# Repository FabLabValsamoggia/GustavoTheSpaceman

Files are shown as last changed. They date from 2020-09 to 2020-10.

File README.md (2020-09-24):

# Gustavo the Spaceman

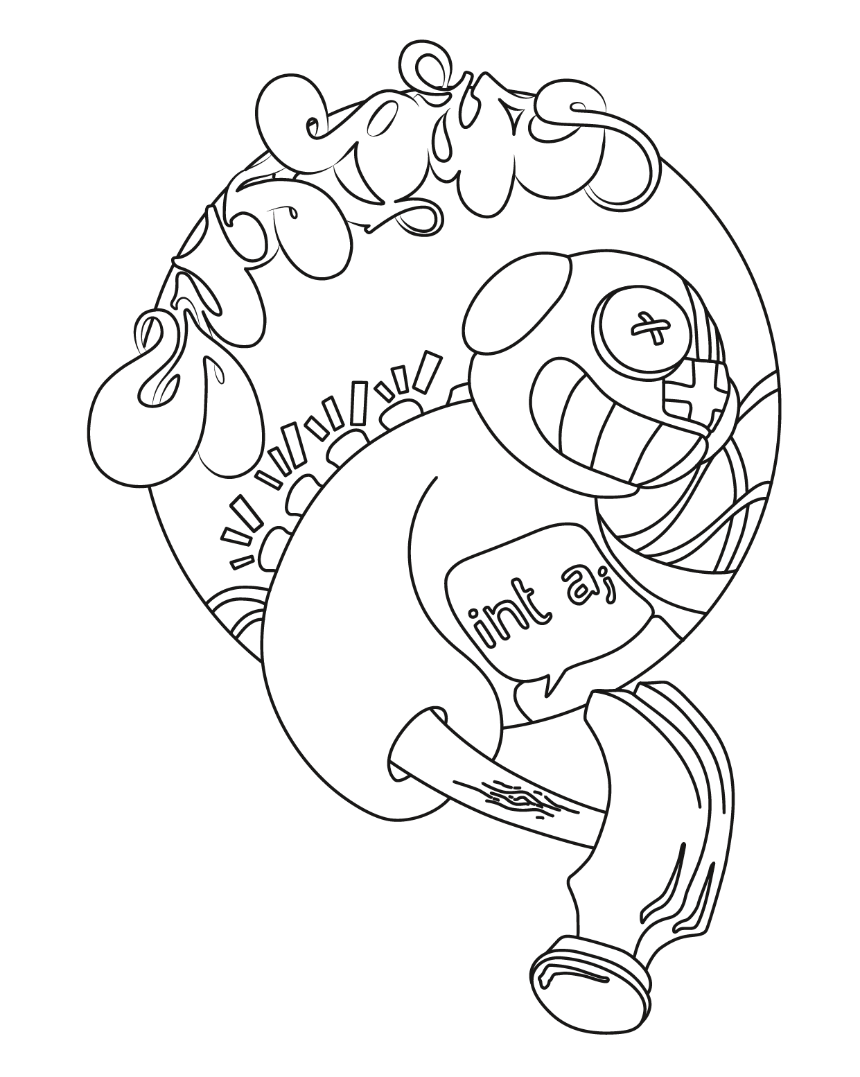
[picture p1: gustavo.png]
Gustavo


developed with ♥ by FabLab Valsamoggia

**Gustavo the spaceman** is an educational puppet kit that can help educators and teachers to teach and experiment 3D printing, electronics and coding with children. Students can customize the puppet by adding details and tools using a 3D modeling software. Then with Arduino IDE and Blockly they can program lights and sounds to create their own character. The kit is made of a 3D printed puppet with some holes for additional parts, one Arduino Nano with USB cable, a shield with 16 LEDs and 4 buttons, a small speaker and a miniSD card reader to upload sounds.

## Contributing
Pull requests are welcome. For major changes, please open an issue first to discuss what you would like to change.

Please make sure to update tests as appropriate.

## License
[MIT](https://choosealicense.com/licenses/mit/)

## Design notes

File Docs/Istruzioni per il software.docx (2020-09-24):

Istruzioni per i vari software

1. Caricare le librerie in Arduino: ci sono due modi per caricare le librerie
  a. Metodo veloce (se è presente connessione wifi):
    i. Aprire IDE Arduino
    ii. andare in Sketch → #include librerie → gestione librerie
    iii. Nella schermata che appare cercare
      1. Adafruit NeoPixel (libreria per i led creata da Adafruit)
      2. DFRobotDFPlayerMini (libreria per il modulo mp3 da DFRobot)
  b. Metodo meno veloce (copiare le librerie da google drive (nella cartella Librerie Arduino) in Documenti → Arduino → libraries
2. Alcune note per i programmi:
  a. Tasti_e_Led: il programma setta i colori dei led (tutti e 16) del colore desiderato. Per farlo le istruzioni importanti sono

red = 0;
green = 0;
blue = 75;
matrix_color = matrix.Color(red, green, blue);
for (int i = 0; i < MATRIX_NLED; i++)
{
matrix.setPixelColor(i, matrix_color);
matrix.show();
}

red, green, blue settano il colore dei led in formato RGB; tutte e tre possono assumere valori da 0 a 255. Essi inoltre controllano la luminosità dei led . Per esempio red = 75, green = 0, blue = 0 e red = 255, green = 0, blue = 0 creano entrambi il colore rosso, ma il secondo sarà molto più luminoso.

matrix.Color mischia i tre colori.

Il ciclo for serve per accendere tutti i led. In realtà si possono accendere anche solo alcuni led o anche led singoli per esempio

for (int i = 0; i < 4; i++)
{
matrix.setPixelColor(i, matrix_color);
matrix.show();
}

accende solo i primi 4 led mentre

matrix.setPixelColor(7, matrix_color);
matrix.show();

accende solo il led numero 7

Per spegnere i led basta settare

red = 0;
green = 0;
blue = 0;
matrix_color = matrix.Color(red, green, blue);

b. Tasti_e_mp3: qui c’è poco da aggiungere. Le istruzioni sono quelle e devono essere così eseguite altrimenti non funzionano. Nell’ esempio completo di libreria però (accessibili dall’IDE arduino tramite file→ esempi→ DFRobotMini→ FullFunction) sono presenti tutte le istruzioni che puoi far eseguire al modulo mp3.

Nota Bene: nella cartella drive, all’interno di mp3Completo ho inserito una cartella microSD; all’interno c’è come devono essere inseriti i brani per fare in modo che vengano letti correttamente. In pratica dentro la SD bisogna creare una cartella mp3 e all’interno rinumerare i suoni in 0001, 0002 ecc

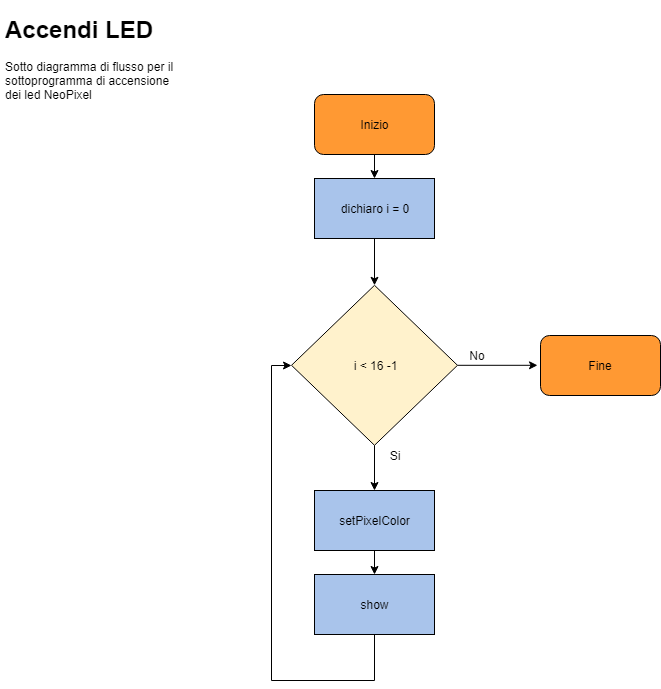
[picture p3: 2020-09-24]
Docs/Accendi Led.png

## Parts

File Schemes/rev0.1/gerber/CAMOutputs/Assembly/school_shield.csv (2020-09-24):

Qty | Value | Device | Package | Parts | Description | MPN | OC_FARNELL | OC_NEWARK | PACKAGE | PROD_ID | SPICEPREFIX | SUPPLIER
1 |  | 47346-0001 | MOLEX_47346-0001 | J1 | CONN RCPT 5POS MICRO USB R/A SMD | 47346-0001 | 1568026 | 47M0505 | 5 POS MICRO USB R/A |  | X | MOLEX
1 |  | DIODESMA | SMA-DIODE | D1 | Diode
2 |  | FE08-1SMD | FE08_SMD | SV3, SV4 | FEMALE HEADER
2 |  | FE15-1SMD | FE15_SMD | SV1, SV2 | FEMALE HEADER
14 | 10K S | R-EU_R0805 | R0805 | R1, R3, R5, R7, R9, R10, R12, R13, R15, R18, R19, R20, R21, R22 | RESISTOR, European symbol
1 | 10R S | R-EU_R0805 | R0805 | R2 | RESISTOR, European symbol
2 | 10uF | C-EUC0805 | C0805 | C203, C205 | CAPACITOR, European symbol
1 | 10uF S | C-EUC0805 | C0805 | C1 | CAPACITOR, European symbol
2 | 1K S | R-EU_R0805 | R0805 | R16, R17 | RESISTOR, European symbol
4 | 1uF | C-EUC0805 | C0805 | C2, C3, C4, C202 | CAPACITOR, European symbol
1 | 330R S | R-EU_R0805 | R0805 | R6 | RESISTOR, European symbol
1 | 53047-02 | 53047-02 | 53047-02 | X1 | CONNECTOR
1 | FABLAB | FABLAB | FABLAB | U$1
1 | LM4871M | LM4871M | SOIC127P600X175-8N | U1 | Power Amplifier | LM4871M | 1468873 | 41K5780 | SOIC-8 |  |  | NationalSemiconductor
1 | OSHW-LOGOMINI | OSHW-LOGOMINI | OSHW-LOGO-MINI | LOGO1 | Open Source Hardware Logo
4 | PHOTOCELLPTH | PHOTOCELLPTH | PHOTOCELL | R4, R8, R11, R14 | CdS photoresistor. This is a low cost way to detect light levels. Resistance decreases with more incoming light. SparkFun SKU: SEN-09088
4 | SMD_SWT | SWITCH-MOMENTARY-2SMD-4 | TACTILE_SWITCH_TALL | S1, S2, S3, S4 | Various NO switches- pushbuttons, reed, etc |  |  |  |  | SWCH-11966
1 | Si2309DS | MOSFET-PCHANNELSMD | SOT23-3 | Q1 | Generic PMOSFET
16 | WS2812B_ALT | WS2812B_ALT | WS2812B | LED1, LED2, LED3, LED4, LED5, LED6, LED7, LED8, LED9, LED10, LED11, LED12, LED13, LED14, LED15, LED16

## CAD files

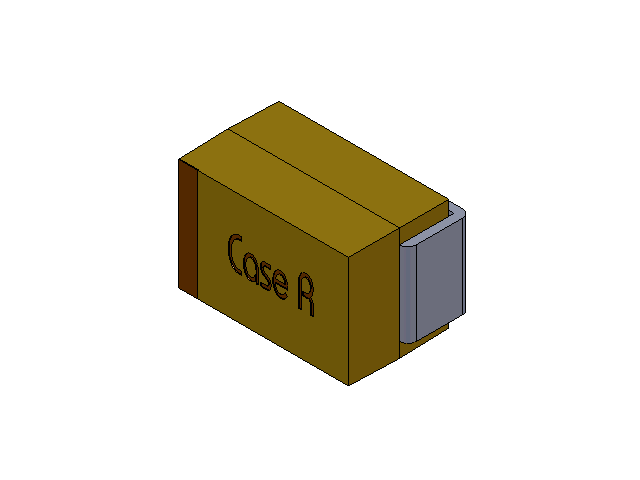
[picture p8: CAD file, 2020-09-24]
Mec/Arduino Nano/Solidworks/User Library-Arduino Nano 3.0_User Library-Tantalum Capacitor Case R.SLDASM
User Library-Arduino Nano 3.0_User Library-Tantalum Capacitor Case R_Tantalum case R part1
User Library-Arduino Nano 3.0_User Library-Tantalum Capacitor Case R_Tantalum case R part2 x 2

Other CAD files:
Mec/Modulo mp3/User Library-MP3-TF-16P_Designator37.sldasm
Mec/Arduino Nano/Solidworks/User Library-Arduino Nano 3.0_User Library-CSTCE_V-1_453331041.sldasm
Mec/Modulo mp3/User Library-MP3-TF-16P_Designator5.sldasm
Mec/Modulo mp3/User Library-MP3-TF-16P_Designator17.sldasm
Mec/Arduino Nano/Solidworks/User Library-Arduino Nano 3.0_User Library-CSTCE_V-1_453563985.sldasm
Mec/Modulo mp3/User Library-MP3-TF-16P_Designator42.sldasm
Mec/Arduino Nano/Solidworks/User Library-Arduino Nano 3.0_User Library-CSTCE_V-1_453563729.sldasm
Mec/Modulo mp3/User Library-MP3-TF-16P_1464623456.sldasm
Mec/Arduino Nano/Solidworks/User Library-Arduino Nano 3.0_User Library-CSTCE_V-1_453566289.sldasm
Mec/Modulo mp3/User Library-MP3-TF-16P_Designator44.sldasm
Mec/Modulo mp3/User Library-MP3-TF-16P_Designator9.sldasm
Mec/Modulo mp3/User Library-MP3-TF-16P_Designator19.sldasm
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

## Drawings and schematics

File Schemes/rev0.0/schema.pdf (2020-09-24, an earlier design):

A

A

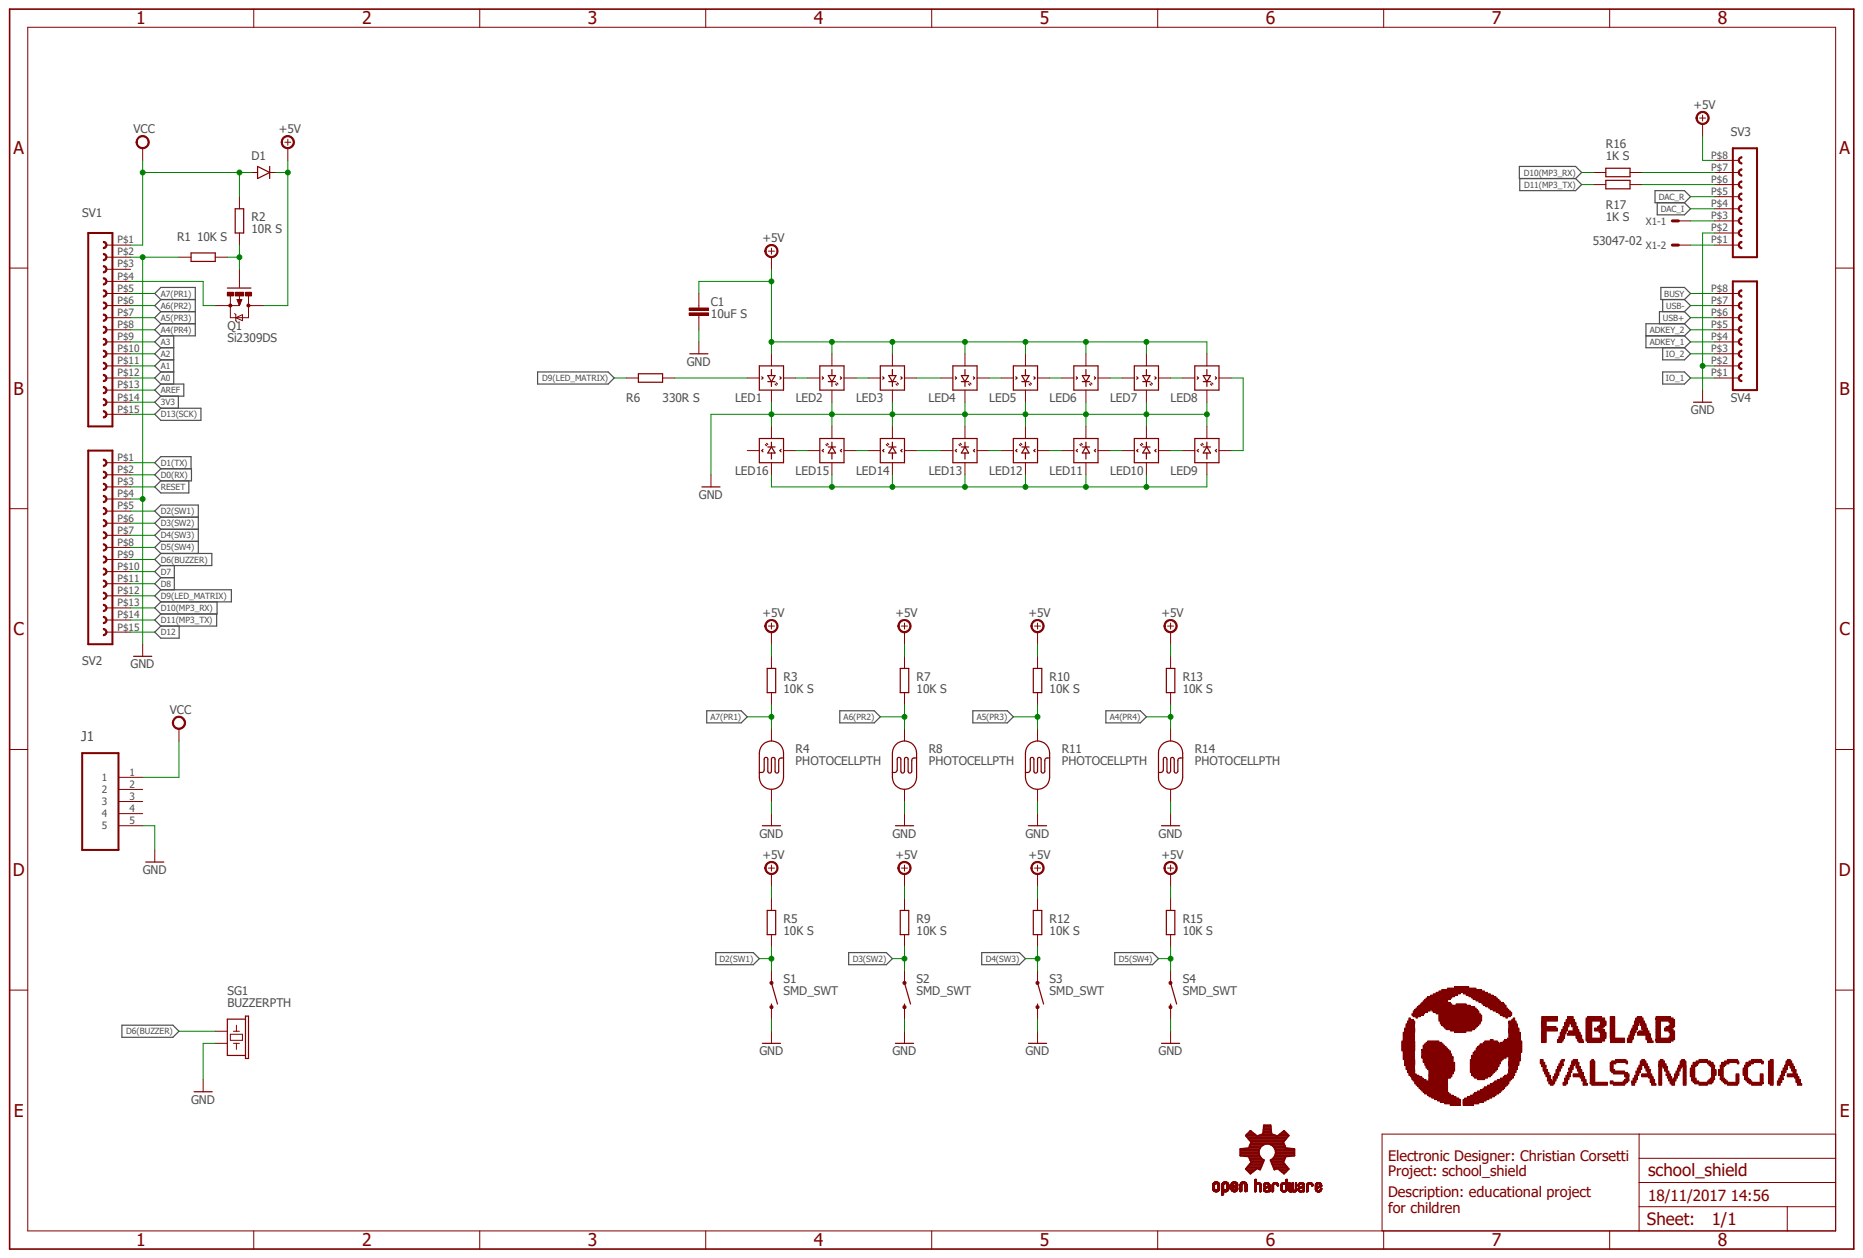
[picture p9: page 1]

Electronic Designer: Christian Corsetti Project: school_shield Description: educational project for children

Sheet: 1/1

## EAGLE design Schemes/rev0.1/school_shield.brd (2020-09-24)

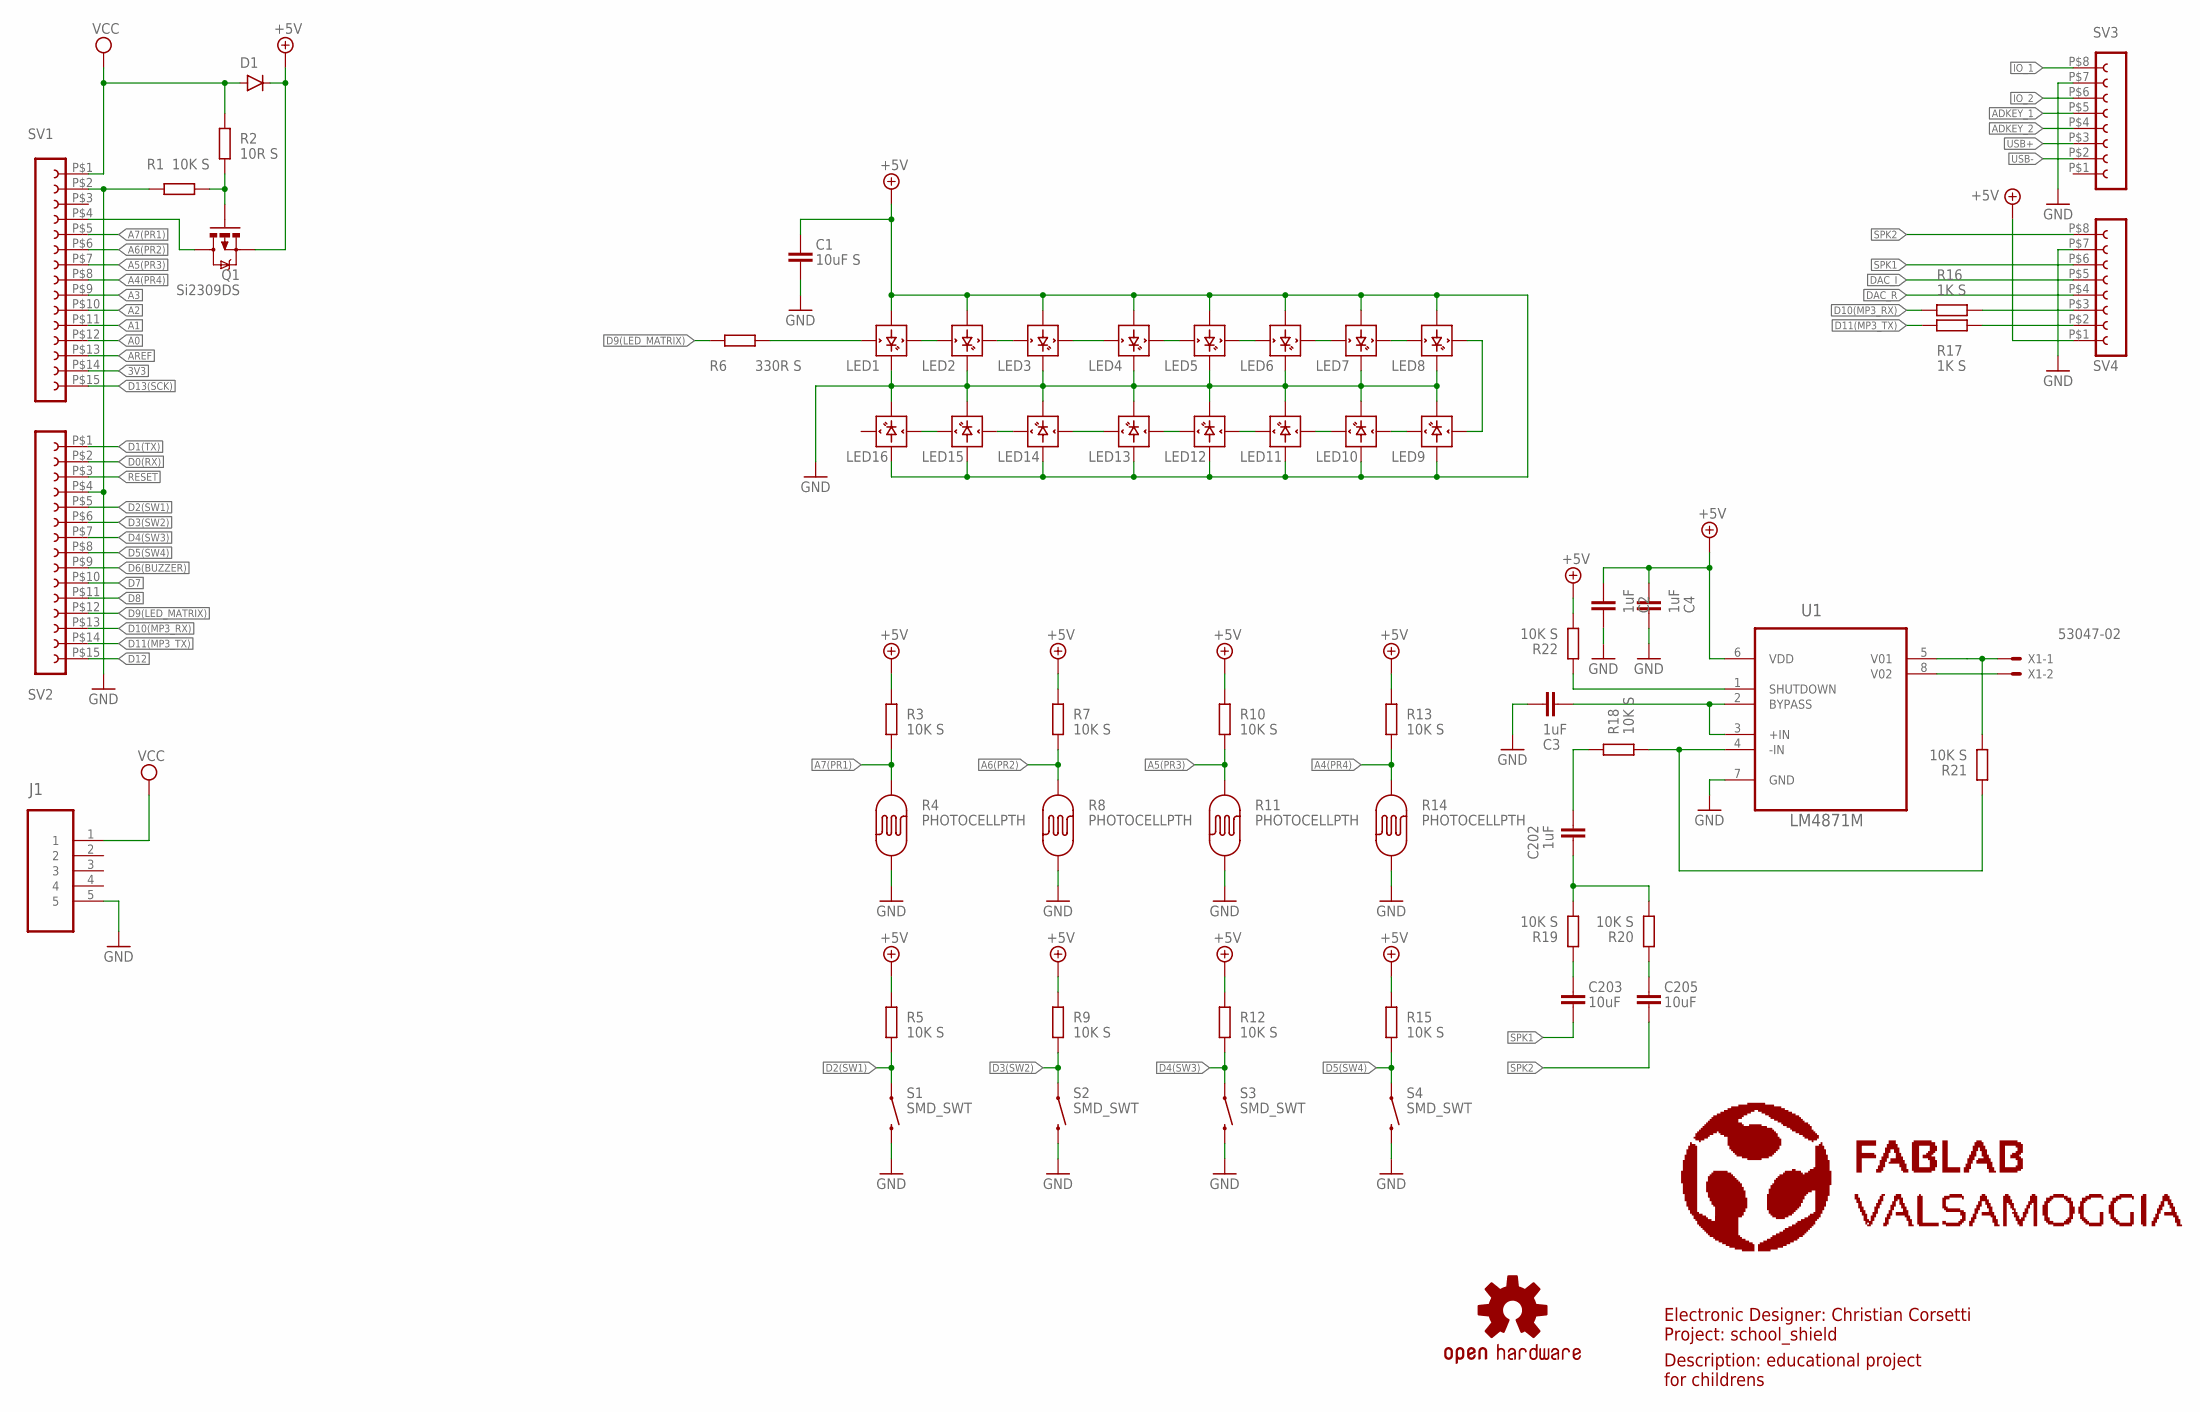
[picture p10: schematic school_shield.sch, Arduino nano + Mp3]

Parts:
C1: 10uF S; C0805
C2, C3, C4, C202: 1uF; C0805
C203, C205: 10uF; C0805
D1: DIODESMA; SMA-DIODE
J1: 47346-0001; MOLEX_47346-0001
LED1, LED2, LED3, LED4, LED5, LED6, LED7, LED8, LED9, LED10, LED11, LED12, LED13, LED14, LED15, LED16: WS2812B_ALT; WS2812B
LOGO1: OSHW-LOGOMINI; OSHW-LOGO-MINI
Q1: Si2309DS; SOT23-3
R1, R3, R5, R7, R9, R10, R12, R13, R15, R18, R19, R20, R21, R22: 10K S; R0805
R2: 10R S; R0805
R4, R8, R11, R14: PHOTOCELLPTH; PHOTOCELL
R6: 330R S; R0805
R16, R17: 1K S; R0805
S1, S2, S3, S4: SMD_SWT; TACTILE_SWITCH_TALL
SV1, SV2: FE15-1SMD; FE15_SMD
SV3, SV4: FE08-1SMD; FE08_SMD
U1: LM4871M; SOIC127P600X175-8N
U$1: FABLAB
X1: 53047-02

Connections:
3V3: SV1.P$14 (14)
+5V: C1.2, C2.1, C4.1, D1.C, LED1.1-VDD (VDD), LED2.1-VDD (VDD), LED3.1-VDD (VDD), LED4.1-VDD (VDD), LED5.1-VDD (VDD), LED6.1-VDD (VDD), LED7.1-VDD (VDD), LED8.1-VDD (VDD), LED9.1-VDD (VDD), LED10.1-VDD (VDD), LED11.1-VDD (VDD), LED12.1-VDD (VDD), LED13.1-VDD (VDD), LED14.1-VDD (VDD), LED15.1-VDD (VDD), LED16.1-VDD (VDD), Q1.2 (S), R3.2, R5.2, R7.2, R9.2, R10.2, R12.2, R13.2, R15.2, R22.1, SV4.P$1 (1), U1.6 (VDD)
A0: SV1.P$12 (12)
A1: SV1.P$11 (11)
A2: SV1.P$10 (10)
A3: SV1.P$9 (9)
A4(PR4): R13.1, R14.2, SV1.P$8 (8)
A5(PR3): R10.1, R11.2, SV1.P$7 (7)
A6(PR2): R7.1, R8.2, SV1.P$6 (6)
A7(PR1): R3.1, R4.2, SV1.P$5 (5)
ADKEY_1: SV3.P$5 (5)
ADKEY_2: SV3.P$4 (4)
AREF: SV1.P$13 (13)
AUDIO: R18.1, R21.2, U1.4 (-IN)
D0(RX): SV2.P$2 (2)
D1(TX): SV2.P$1 (1)
D2(SW1): R5.1, S1.A2 (1), SV2.P$5 (5)
D3(SW2): R9.1, S2.A2 (1), SV2.P$6 (6)
D4(SW3): R12.1, S3.A2 (1), SV2.P$7 (7)
D5(SW4): R15.1, S4.A2 (1), SV2.P$8 (8)
D6(BUZZER): SV2.P$9 (9)
D7: SV2.P$10 (10)
D8: SV2.P$11 (11)
D9(LED_MATRIX): R6.2, SV2.P$12 (12)
D10(MP3_RX): R16.2, SV2.P$13 (13)
D11(MP3_TX): R17.2, SV2.P$14 (14)
D12: SV2.P$15 (15)
D13(SCK): SV1.P$15 (15)
DAC_I: SV4.P$5 (5)
DAC_R: SV4.P$4 (4)
GND: C1.1, C2.2, C3.2, C4.2, J1.5, LED1.3-GND (GND), LED2.3-GND (GND), LED3.3-GND (GND), LED4.3-GND (GND), LED5.3-GND (GND), LED6.3-GND (GND), LED7.3-GND (GND), LED8.3-GND (GND), LED9.3-GND (GND), LED10.3-GND (GND), LED11.3-GND (GND), LED12.3-GND (GND), LED13.3-GND (GND), LED14.3-GND (GND), LED15.3-GND (GND), LED16.3-GND (GND), R1.2, R4.1, R8.1, R11.1, R14.1, S1.B2 (2), S2.B2 (2), S3.B2 (2), S4.B2 (2), SV1.P$2 (2), SV2.P$4 (4), SV3.P$7 (7), SV4.P$7 (7), U1.7 (GND)
IO_1: SV3.P$8 (8)
IO_2: SV3.P$6 (6)
unnamed: Q1.1 (G), R1.1, R2.2
unnamed: C3.1, U1.2 (BYPASS), U1.3 (+IN)
unnamed: Q1.3 (D), SV1.P$4 (4)
unnamed: LED1.4-DIN (DIN), R6.1
unnamed: C205.1, R20.2
unnamed: C203.1, R19.2
unnamed: C202.1, R19.1, R20.1
unnamed: R22.2, U1.1 (SHUTDOWN)
unnamed: R21.1, U1.5 (V01), X1.1
unnamed: C202.2, R18.2
unnamed: U1.8 (V02), X1.2
unnamed: LED1.2-DOUT (DOUT), LED2.4-DIN (DIN)
unnamed: LED2.2-DOUT (DOUT), LED3.4-DIN (DIN)
unnamed: LED3.2-DOUT (DOUT), LED4.4-DIN (DIN)
unnamed: LED4.2-DOUT (DOUT), LED5.4-DIN (DIN)
unnamed: LED5.2-DOUT (DOUT), LED6.4-DIN (DIN)
unnamed: LED6.2-DOUT (DOUT), LED7.4-DIN (DIN)
unnamed: LED7.2-DOUT (DOUT), LED8.4-DIN (DIN)
unnamed: LED8.2-DOUT (DOUT), LED9.4-DIN (DIN)
unnamed: LED9.2-DOUT (DOUT), LED10.4-DIN (DIN)
unnamed: LED10.2-DOUT (DOUT), LED11.4-DIN (DIN)
unnamed: LED11.2-DOUT (DOUT), LED12.4-DIN (DIN)
unnamed: LED12.2-DOUT (DOUT), LED13.4-DIN (DIN)
unnamed: LED13.2-DOUT (DOUT), LED14.4-DIN (DIN)
unnamed: LED14.2-DOUT (DOUT), LED15.4-DIN (DIN)
unnamed: LED15.2-DOUT (DOUT), LED16.4-DIN (DIN)
unnamed: R16.1, SV4.P$3 (3)
unnamed: R17.1, SV4.P$2 (2)
RESET: SV2.P$3 (3)
SPK1: C203.2, SV4.P$6 (6)
SPK2: C205.2, SV4.P$8 (8)
USB+: SV3.P$3 (3)
USB-: SV3.P$2 (2)
VCC: D1.A, J1.1, R2.1, SV1.P$1 (1)

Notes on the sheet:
Electronic Designer: Christian Corsetti Project: school_shield
Description: educational project for childrens

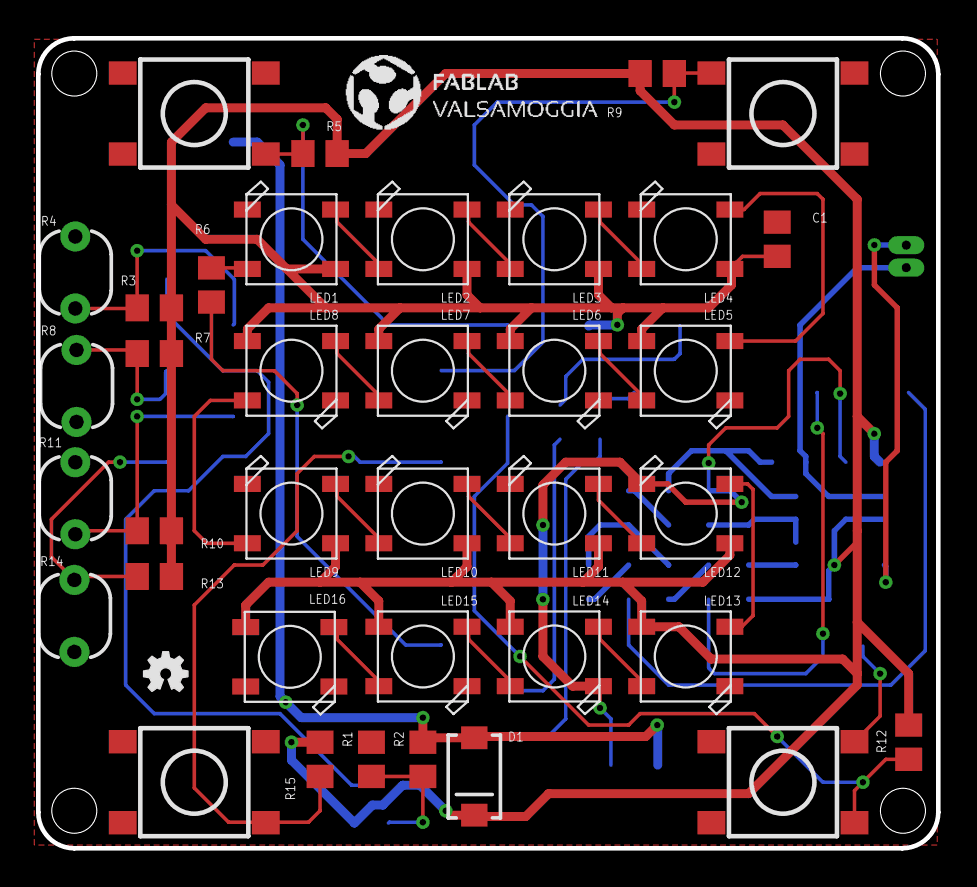
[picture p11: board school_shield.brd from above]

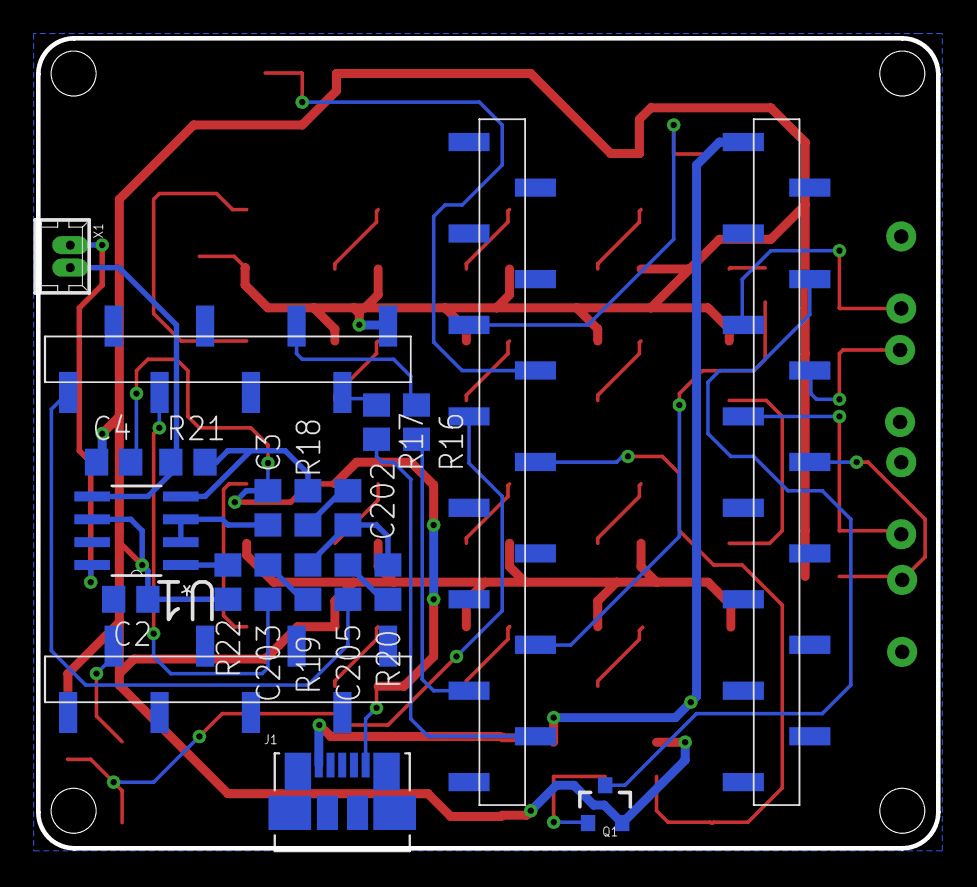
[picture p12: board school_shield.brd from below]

Board: 2 copper layers, 50.0 x 45.0 mm, 60 parts (21 on the bottom side), 45 nets.

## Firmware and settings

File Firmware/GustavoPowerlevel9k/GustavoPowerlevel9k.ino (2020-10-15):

/******************************************************************************/
/* school_shield.ino                                        Data: 18/01/2018  */
/* Descrizione: programma di esempio e di sviluppo per il progetto            */
/*              school_shield sviluppato al FabLab Valsamoggia                */
/* Versione:    0.00                                                          */
/* Modifiche:                                                                 */
/*              Christian Corsetti (18/01/2018)                               */
/*              Creazione programma                                           */
/*              Christian Corsetti (18/01/2018)                               */
/*              Test dei tasti e aggiunta funzioni separate per la gestione   */
/*              Christian Corsetti (19/01/2018)                               */
/*              Test delle fotoresistenze e aggiunte funzioni separate        */
/*              Christian Corsetti (29/01/2018)                               */
/*              Trasporto del progetto da Platformio a IDE Arduino            */
/*              Pulizia del codice e commenti per rendere più chiare le       */
/*              varie parti del programma                                     */
/*              Christian COrsetti (03/02/2018)                               */
/*              Aggiunto il controllo di luminosità tramite fotoresistenze    */
/*              Aggiunte le funzioni phts_init, phts_check_state e relativo   */
/*              codice per il funzionamento in setup e loop                   */
/*              Christian Corsetti (04/02/2018)                               */
/*              Aggiunta rainbowCycle                                         */
/*              Inizio spostamento funzioni principali per creazione libreria */
/*              Pulizia codice e commenti delle parti principali              */
/*              Bug fix su scarsa sensibilità per il cambiamento di           */
/*              Luminosità                                                    */
/******************************************************************************/
/* 
 * This program is free software: you can redistribute it and/or modify  
 * it under the terms of the GNU General Public License as published by  
 * the Free Software Foundation, version 3.
 *
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
 * You should have received a copy of the GNU General Public License 
 * along with this program. If not, see <http://www.gnu.org/licenses/>.
 */
/*----------------------------------------------------------------------------*/
/* Includes                                                                   */
/*----------------------------------------------------------------------------*/
#include "Adafruit_NeoPixel.h"          // Libreria per la gestione led
#include "Timer.h"                      // Libreria gestione timer
#include "struttura_hardware.h"
#include "SoftwareSerial.h"
#include "DFRobotDFPlayerMini.h"
/*----------------------------------------------------------------------------*/
/* Defines                                                                    */
/*----------------------------------------------------------------------------*/
#define TIMEOUT             100
#define PERIOD              60000       
#define THRESHOLD           50
/*----------------------------------------------------------------------------*/
/* Variables                                                                  */
/*----------------------------------------------------------------------------*/
/*== Variabili Locali ========================================================*/

/*== Variabili Globali =======================================================*/
uint32_t matrix_color    ;  // Contiene il colore con cui si accendono i led
int luminosity = 75      ;  // Contiene la luminosità che avranno i led
uint8_t btn              ;  // Contiene quale tasto è stato premuto
uint8_t pht              ;
/*== Variabili Definite ======================================================*/
Adafruit_NeoPixel matrix ;  // Classe per la gestione dei Led
matrix_rgb_t matrix_rgb  ;  // contiene il colore in RGB (RED, GREEN, BLUE)
Timer t;                    // variabile per il funzionamento del timer
phts_t photoR1;
phts_t photoR2;
phts_t photoR3;
phts_t photoR4;

btn_state_t btn1;
btn_state_t btn2;
btn_state_t btn3;
btn_state_t btn4;

DFRobotDFPlayerMini myDFPlayer;
SoftwareSerial mySoftwareSerial(11, 10);
unsigned int volume = 15;
/*----------------------------------------------------------------------------*/
/* Prototypes                                                                 */
/*----------------------------------------------------------------------------*/
void whiteOverRainbow(uint8_t wait, uint8_t whiteSpeed, uint8_t whiteLength );
void printDetail(uint8_t type, int value);
/*----------------------------------------------------------------------------*/
/* phts_init                                                                  */
/* Descrizione: Inizializza la parte hardware relativa alle fotoresistenze    */
/* Return     : void                                                          */
/*----------------------------------------------------------------------------*/
void phts_init(void)
{
  /*==========================================================================*/
  /* Leggo i valori delle fotoresistenze all'accensione. Questi saranno i     */
  /* valori di riferimento per il cambiamento di luminosità.                  */
  /* N.B: questa implementazione è la maniera più semplicema presenta un bug. */
  /* Passando in un luogo con fonte luminosa differente, i led potrebbero     */
  /* cambiare automaticamente il valore di luminosità. Questo è dovuto al     */
  /* fatto che i valori letti durante il run time del programma potrebbero    */
  /* essere fuori soglia (vedi phts_check_state per dettagli) senza coprire   */
  /* le fotoresistenze. Il metodo migliore per eliminare questo bug è         */
  /* cambiare la soglia fino a trovare il migliore compromesso possibile.     */
  /* Per eliminare del tutto il problema, implementare un PID                 */
  /*==========================================================================*/
  photoR1.old_val = analogRead(PHOTO1);
  photoR2.old_val = analogRead(PHOTO2);
  photoR3.old_val = analogRead(PHOTO3);
  photoR4.old_val = analogRead(PHOTO4);
#ifdef DEBUG
  Serial.println("valori iniziali");
  Serial.println(photoR1.old_val);
  Serial.println(photoR2.old_val);
  Serial.println(photoR3.old_val);
  Serial.println(photoR4.old_val);
#endif
}
/*----------------------------------------------------------------------------*/
/* phts_check_state                                                           */
/* Descrizione: legge il valore attuale delle fotoresistenze                  */
/* Return     : 1 se sono "coperte" photoR1 e/o photoR2                       */
/*              2 se sono "coperte" photoR3 e/o photoR4                       */
/*              0 se non è stato "coperto" niente                             */
/*----------------------------------------------------------------------------*/
uint8_t phts_check_state(void)
{
  photoR1.val = analogRead(PHOTO1);
  photoR2.val = analogRead(PHOTO2);
  photoR3.val = analogRead(PHOTO3);
  photoR4.val = analogRead(PHOTO4);
#ifdef DEBUG
  Serial.println(photoR1.val);
  Serial.println(photoR2.val);
  Serial.println(photoR3.val);
  Serial.println(photoR4.val);
  Serial.println("\r\n");
  Serial.println("\r\n");
#endif
  if ((photoR1.val > photoR1.old_val + THRESHOLD) || (photoR2.val > photoR2.old_val + THRESHOLD))
    return (1);
  if ((photoR3.val > photoR3.old_val + THRESHOLD) || (photoR4.val > photoR4.old_val + THRESHOLD))
    return (2);

  return (0);
}

uint8_t btns_check_state(uint16_t debounce)
{
    /*-------------------------------------------------*/
    /*                    TASTO 1                      */
    /*-------------------------------------------------*/
    /* leggo il valore del tasto */
    btn1.val = digitalRead(BTN1);
    /* controllo sia diverso dal valore letto prima */
    if((btn1.val == LOW) && (btn1.old_val == HIGH))
    {
        /* debounce del tasto */
        delay(debounce);
        /* rilettura del tasto */
        btn1.val = digitalRead(BTN1);
        if(btn1.val == LOW)
        {
            return(1);
        }
    }
    /*-------------------------------------------------*/
    /*                    TASTO 2                      */
    /*-------------------------------------------------*/
    /* leggo il valore del tasto */
    btn2.val = digitalRead(BTN2);
    /* controllo sia diverso dal valore letto prima */
    if((btn2.val == LOW) && (btn2.old_val == HIGH))
    {
        /*debounce del tasto */
        delay(debounce);
        /* rilettura del tasto */
        btn2.val = digitalRead(BTN2);
        if(btn2.val == LOW)
        {
            return(2);
        }
    }
    /*-------------------------------------------------*/
    /*                    TASTO 3                      */
    /*-------------------------------------------------*/
    /* leggo il valore del tasto */
    btn3.val = digitalRead(BTN3);
    /* controllo sia diverso dal valore letto prima */
    if((btn3.val == LOW) && (btn3.old_val == HIGH))
    {
        /*debounce del tasto */
        delay(debounce);
        /* rilettura del tasto */
        btn3.val = digitalRead(BTN3);
        if(btn3.val == LOW)
        {
            return(3);
        }
    }
    /*-------------------------------------------------*/
    /*                    TASTO 4                      */
    /*-------------------------------------------------*/
    /* leggo il valore del tasto */
    btn4.val = digitalRead(BTN4);
    /* controllo sia diverso dal valore letto prima */
    if((btn4.val == LOW) && (btn4.old_val == HIGH))
    {
        /*debounce del tasto */
        delay(debounce);
        /* rilettura del tasto */
        btn4.val = digitalRead(BTN4);
        if(btn4.val == LOW)
        {
            return(4);
        }
    }
    /* setto il valore letto come vecchio valore */
    btn1.old_val = btn1.val;
    btn2.old_val = btn2.val;
    btn3.old_val = btn3.val;
    btn4.old_val = btn4.val;
    return(0);
}
/*----------------------------------------------------------------------------*/
/* SpegniLed                                                                  */
/* Descrizione: funzione interrupt attivata ogni x secondi dal timer.         */
/*              Verifica se ci sono tasti premuti e in caso negativo, spegne  */
/*              i led                                                         */
/* Return     : void                                                          */
/*----------------------------------------------------------------------------*/
void SpegniLed()
{
  if (!btns_check_state(20))
  {
    matrix_rgb.r = 0;
    matrix_rgb.g = 0;
    matrix_rgb.b = 0;
    matrix_color = matrix.Color(luminosity * matrix_rgb.r,
                                luminosity * matrix_rgb.g,
                                luminosity * matrix_rgb.b);

    /* Accendo i led con il colore selezionato tramite il tasto */
    for (int i = 0; i < MATRIX_NLED; i++)
    {
      matrix.setPixelColor(i, matrix_color);
      matrix.show();
      delay(TIMEOUT);
    }
  }
}
/*----------------------------------------------------------------------------*/
/* setup()                                                                    */
/* Descrizione: Funzione per inizializzare tutto l'hardware necessario per    */
/*              il funzionamento corretto del programma                       */
/* Return     : void                                                          */
/*----------------------------------------------------------------------------*/
void setup()
{
  mySoftwareSerial.begin(9600);
  /* Inzializzo la comunicazione seriale           */
  Serial.begin(115200);

  Serial.println();
  Serial.println(F("DFRobot DFPlayer Mini Demo"));
  Serial.println(F("Initializing DFPlayer ... (May take 3~5 seconds)"));

   if (!myDFPlayer.begin(mySoftwareSerial)) {  //Use softwareSerial to communicate with mp3.
    Serial.println(F("Unable to begin:"));
    Serial.println(F("1.Please recheck the connection!"));
    Serial.println(F("2.Please insert the SD card!"));
    while(true){
      delay(0); // Code to compatible with ESP8266 watch dog.
    }
  }
  Serial.println(F("DFPlayer Mini online."));
  
  myDFPlayer.volume(volume);  //Set volume value. From 0 to 30
  myDFPlayer.play(1);  //Play the first mp3
  
  /* Inizializzo la striscia di led */
  matrix = Adafruit_NeoPixel(MATRIX_NLED, MATRIX_PLED,
                             NEO_GRB + NEO_KHZ800);
  /*===============================================*/
  /* Una volta inizializzata, posso far partire    */
  /* tutti i processi che servono per poter        */
  /* utilizzare i led nel modo giusto              */
  /*===============================================*/
  matrix.begin();
  /* parto con i led spenti */
  matrix.show();
  /*===============================================*/
  /* Inizializzo i tasti. Siccome devo leggere     */
  /* lo stato in cui si trovano li inizializzo     */
  /* come input.                                   */
  /* N.B. : per questioni hardware, lo stato 0     */
  /* indica tasto premuto, lo stato 1 indica       */
  /* non premuto                                   */
  /*===============================================*/
  pinMode(BTN1, INPUT);
  pinMode(BTN2, INPUT);
  pinMode(BTN3, INPUT);
  pinMode(BTN4, INPUT);
  /* Inizializzo lo stato delle fotoresistenze     */
  phts_init();

  /* Inizializzo il timer per l'interrupt          */
  int tickEvent = t.every(PERIOD, SpegniLed);
}
/*----------------------------------------------------------------------------*/
/* setup()                                                                    */
/* Descrizione: Parte di programma che si ripete all'infinito. Contiene tutto */
/*              il codice che serve per far funzionare l'algoritmo del        */
/*              programma                                                     */
/* Return     : void                                                          */
/*----------------------------------------------------------------------------*/
void loop()
{
  /* Refresh del timer */
  t.update();
  if (myDFPlayer.available()) 
  {
    printDetail(myDFPlayer.readType(), myDFPlayer.read());
  }
  /* leggo lo stato attuale delle fotoresistenze */
  pht = phts_check_state();
  
  switch (pht)
  {
    case 1:
      if (luminosity < 255)
      {
        luminosity += 10;
      }
      break;
    case 2:
      if (luminosity < 255)
      {
        luminosity += 50;
      }
      break;
    case 3:
      if (luminosity > 1)
      {
        luminosity -= 10;
      }
      break;
    case 4:
      if (luminosity > 1)
      {
        luminosity -= 50;
      }
      break;
    default:
      break;
  }
  if (luminosity > 255)
    luminosity = 255;
  if (luminosity < 1)
    luminosity = 1;
  Serial.println(luminosity);

  btn = btns_check_state(20);
  switch (btn)
  {
    case 1:
      /*===================================================*/
      /* Se il tasto premuto è il primo, setto il colore   */
      /* dei led blu                                       */
      /*===================================================*/
      matrix_rgb.r = 0;
      matrix_rgb.g = 0;
      matrix_rgb.b = 1;
      matrix_color = matrix.Color(luminosity * matrix_rgb.r,
                                  luminosity * matrix_rgb.g,
                                  luminosity * matrix_rgb.b);
      break;
    case 2:
      /*===================================================*/
      /* Se il tasto premuto è il secondo, setto il colore */
      /* dei led verde                                     */
      /*===================================================*/
      //matrix_rgb.r = 0;
      //matrix_rgb.g = 1;
      //matrix_rgb.b = 0;
      //matrix_color = matrix.Color(luminosity * matrix_rgb.r,
        //                          luminosity * matrix_rgb.g,
          //                        luminosity * matrix_rgb.b);
      if(volume < 30)
      {
        volume++;
        myDFPlayer.volume(volume);
      }
      break;
    case 3:
      /*===================================================*/
      /* Se il tasto premuto è il terzo, setto il colore   */
      /* dei led rosso                                     */
      /*===================================================*/
      //matrix_rgb.r = 1;
      //matrix_rgb.g = 0;
      //matrix_rgb.b = 0;
      //matrix_color = matrix.Color(luminosity * matrix_rgb.r,
        //                          luminosity * matrix_rgb.g,
        //                          luminosity * matrix_rgb.b);
      if(volume > 0)
      {
        volume--;
        myDFPlayer.volume(volume);
      }
      break;
    case 4:
      /*===================================================*/
      /* Se il tasto premuto è il quarto, chiamo la        */
      /* funzione per creare la sequenza arcobaleno nei    */
      /* nei led                                           */
      /*===================================================*/
      //whiteOverRainbow(20, 75, 5);
      rainbowCycle(20);
      break;
    default:
      matrix_color = matrix.Color(luminosity * matrix_rgb.r,
                                  luminosity * matrix_rgb.g,
                                  luminosity * matrix_rgb.b);
      break;
  }

  /* Accendo i led con il colore selezionato tramite il tasto */
  for (int i = 0; i < MATRIX_NLED; i++)
  {
    matrix.setPixelColor(i, matrix_color);
    matrix.show();
    delay(TIMEOUT);
  }
}

void printDetail(uint8_t type, int value){
  switch (type) {
    case TimeOut:
      Serial.println(F("Time Out!"));
      break;
    case WrongStack:
      Serial.println(F("Stack Wrong!"));
      break;
    case DFPlayerCardInserted:
      Serial.println(F("Card Inserted!"));
      break;
    case DFPlayerCardRemoved:
      Serial.println(F("Card Removed!"));
      break;
    case DFPlayerCardOnline:
      Serial.println(F("Card Online!"));
      break;
    case DFPlayerPlayFinished:
      Serial.print(F("Number:"));
      Serial.print(value);
      Serial.println(F(" Play Finished!"));
      myDFPlayer.next();
      break;
    case DFPlayerError:
      Serial.print(F("DFPlayerError:"));
      switch (value) {
        case Busy:
          Serial.println(F("Card not found"));
          break;
        case Sleeping:
          Serial.println(F("Sleeping"));
          break;
        case SerialWrongStack:
          Serial.println(F("Get Wrong Stack"));
          break;
        case CheckSumNotMatch:
          Serial.println(F("Check Sum Not Match"));
          break;
        case FileIndexOut:
          Serial.println(F("File Index Out of Bound"));
          break;
        case FileMismatch:
          Serial.println(F("Cannot Find File"));
          break;
        case Advertise:
          Serial.println(F("In Advertise"));
          break;
        default:
          break;
      }
      break;
    default:
      break;
  }

}
// dato in input un valore tra 0 e 255 restituisce un valore rgb
uint32_t Wheel(byte WheelPos)
{
  WheelPos = 255 - WheelPos;
  if (WheelPos < 85)
  {
    return matrix.Color(255 - WheelPos * 3, 0, WheelPos * 3, 0);
  }
  if (WheelPos < 170)
  {
    WheelPos -= 85;
    return matrix.Color(0, WheelPos * 3, 255 - WheelPos * 3, 0);
  }
  WheelPos -= 170;
  return matrix.Color(WheelPos * 3, 255 - WheelPos * 3, 0, 0);
}

// gioco di colori
void whiteOverRainbow(uint8_t wait, uint8_t whiteSpeed, uint8_t whiteLength )
{
  if (whiteLength >= matrix.numPixels())
  {
    whiteLength = matrix.numPixels() - 1;
  }

  int head = whiteLength - 1;
  int tail = 0;

  int loops = 3;
  int loopNum = 0;

  static unsigned long lastTime = 0;


  while (true) {
    for (int j = 0; j < 256; j++) {
      for (uint16_t i = 0; i < matrix.numPixels(); i++) {
        if ((i >= tail && i <= head)   ||
            (tail > head && i >= tail) ||
            (tail > head && i <= head) )
        {
          matrix.setPixelColor(i, matrix.Color(0, 0, 0, 255 ) );
        }
        else {
          matrix.setPixelColor(i, Wheel(((i * 256 / matrix.numPixels()) + j) & 255));
        }

      }

      if (millis() - lastTime > whiteSpeed) {
        head++;
        tail++;
        if (head == matrix.numPixels()) {
          loopNum++;
        }
        lastTime = millis();
      }

      if (loopNum == loops) return;

      head %= matrix.numPixels();
      tail %= matrix.numPixels();
      matrix.show();
      delay(wait);
    }
  }

}

void rainbowCycle(uint8_t wait)
{
  uint16_t i, j;

  for (j = 0; j < 256 * 5; j++) {
    for (i = 0; i < matrix.numPixels(); i++) {
      matrix.setPixelColor(i, Wheel(((i * 256 / matrix.numPixels()) + j) & 255));
    }
    matrix.show();
    delay(wait);
  }
}

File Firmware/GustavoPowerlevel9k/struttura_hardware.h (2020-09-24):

#ifndef _STR_HARDWARE
#define _STR_HARDWARE
#define MATRIX_PLED         9     // pin per i led (D9)    
#define MATRIX_NLED         16    // numero di led nella matrice
#define BTN1                2     // pin tasto 1
#define BTN2                3     // pin tasto 2
#define BTN3                4     // pin tasto 3
#define BTN4                5     // pin tasto 4 

#define PHOTO1              A7    // pin fotoresistenza 1
#define PHOTO2              A6    // pin fotoresistenza 2
#define PHOTO3              A5    // pin fotoresistenza 3
#define PHOTO4              A4    // pin fotoresistenza 4

typedef struct
{
    bool val     ; /* valore attuale in lettura */
    bool old_val ; /* vecchio valore letto */
}btn_state_t;

typedef struct
{
  int32_t r      ; /* valore rosso da impostare    */
  int32_t g      ; /* valore di verde da impostare */
  int32_t b      ; /* valore di blu da impostare   */
}matrix_rgb_t;

typedef struct
{
  int val        ; /* valore attuale in lettura */
  int old_val    ; /* vecchio valore letto */
}phts_t;
#endif

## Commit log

2020-09-24 add gustavo body
    [coperchio_rpv03.stl]
2020-10-15 move folder for arduino IDE building
2020-10-15 bug fixe: add btns_check_state
    [GustavoPowerlevel9k.ino]
